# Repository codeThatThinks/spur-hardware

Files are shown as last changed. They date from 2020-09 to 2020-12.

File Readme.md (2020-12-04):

# spur-hardware

A physical UEFI boot switch -- PCB design files.

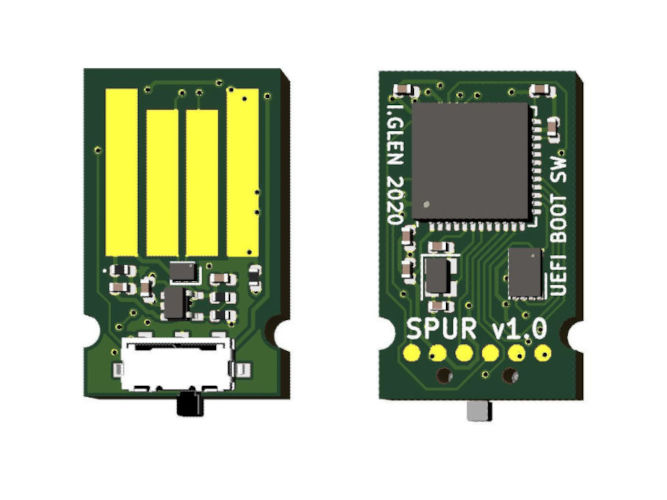
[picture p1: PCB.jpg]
PCB


## Theory of Operation

Spur appears as a virtual USB mass storage device and acts as a first-stage UEFI bootloader. This bootloader loads a specific boot entry in the system UEFI table depending on the position of a physical switch on the device.

A 1MB SPI NOR flash chip contains the FAT32 filesystem on which the UEFI bootloader lives. An STM32F4 microcontroller provides read/write access to the flash over USB. In addition, it presents a virtual file which is read by the bootloader to determine the state of the physical switch.

## License

The MIT License

Copyright 2020 Ian Glen

Permission is hereby granted, free of charge, to any person obtaining a copy of this software and associated documentation files (the "Software"), to deal in the Software without restriction, including without limitation the rights to use, copy, modify, merge, publish, distribute, sublicense, and/or sell copies of the Software, and to permit persons to whom the Software is furnished to do so, subject to the following conditions:

The above copyright notice and this permission notice shall be included in all copies or substantial portions of the Software.

THE SOFTWARE IS PROVIDED "AS IS", WITHOUT WARRANTY OF ANY KIND, EXPRESS OR IMPLIED, INCLUDING BUT NOT LIMITED TO THE WARRANTIES OF MERCHANTABILITY, FITNESS FOR A PARTICULAR PURPOSE AND NONINFRINGEMENT. IN NO EVENT SHALL THE AUTHORS OR COPYRIGHT HOLDERS BE LIABLE FOR ANY CLAIM, DAMAGES OR OTHER LIABILITY, WHETHER IN AN ACTION OF CONTRACT, TORT OR OTHERWISE, ARISING FROM, OUT OF OR IN CONNECTION WITH THE SOFTWARE OR THE USE OR OTHER DEALINGS IN THE SOFTWARE.

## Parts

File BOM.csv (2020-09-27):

Spur v1.0 BOM
Qty. | Refdes | Description | Value | Package | Manufacturer | Manufacturer P/N | Digikey P/N | Unit Price @ Qty 1 | Price @ Qty 1 | Unit Price @ Qty 100 | Price @ Qty 100
2 | C1, C2 | Capacitor, ceramic, 6.3V | 1u | 0402 | Samsung | CL05A105KQ5NNNC | 1276-1010-1-ND | $0.10000 | $0.20 | $0.00870 | $0.02
5 | C3, C7, C8, C9, C10 | Capacitor, ceramic, 6.3V | 0.1u | 0402 | Samsung | CL05A104KQ5NNNC | 1276-1442-1-ND | $0.10000 | $0.50 | $0.00850 | $0.04
2 | C4, C5 | Capacitor, ceramic, 50V | 4p | 0402 | Yageo | CC0402BRNPO9BN4R0 | 311-3705-1-ND | $0.10000 | $0.20 | $0.01760 | $0.04
1 | C6 | Capacitor, ceramic, 10V | 4.7u | 0402 | Samsung | CL05A475MP5NRNC | 1276-1482-1-ND | $0.10000 | $0.10 | $0.00336 | $0.00
1 | D1 | Zener diode, ESD |  | 0402 | ON Semi | NSPU3051N2T5G | NSPU3051N2T5GOSCT-ND | $0.36000 | $0.36 | $0.13440 | $0.13
1 | D2 | Diode array, ESD, 2 channel |  | SOT-886 | Nexperia | PRTR5V0U2F,115 | 1727-4161-1-ND | $0.49000 | $0.49 | $0.25500 | $0.26
1 | PCB1 | Bare PCB, 2 layer, 0.6mm, 1oz, ENIG |  |  | JLCPCB |  |  | $3.60000 | $3.60 | $0.49500 | $0.50
2 | R2, R3 | Resistor, thick film, 1%, 1/16W | 10K | 0402 | Yageo | RC0402FR-0710KL | 311-10.0KLRCT-ND | $0.10000 | $0.20 | $0.00580 | $0.01
1 | R1 | Resistor, thick film, 1%, 1/16W | 23K | 0402 | Yageo | RC0402FR-0722KL | 311-22.0KLRCT-ND | $0.10000 | $0.10 | $0.00580 | $0.01
1 | SW1 | Slide switch, SPDT |  | JS102000SAQN | C&K | JS102000SAQN | 401-2005-1-ND | $0.71000 | $0.71 | $0.56960 | $0.57
1 | U1 | Linear regulator, adjustable, 150mA |  | SOT-353 | Microchip | MIC5377YC5-TR | 576-3358-1-ND | $0.26000 | $0.26 | $0.20000 | $0.20
1 | U2 | Flash memory, NOR, SPI, 1MiB |  | 8-UDFN | Adesto | AT25SF081B-MAHB-T | 1265-AT25SF081B-MAHB-TCT-ND | $0.40000 | $0.40 | $0.32560 | $0.33
1 | U3 | Microcontroller, 128KiB flash |  | 48-UFQFN | STmicro | STM32F401CBU6 | 497-17425-ND | $4.96000 | $4.96 | $3.64690 | $3.65
1 | Y1 | Crystal, 24MHz, Cl=12pF |  | 4-SMD | Murata | XRCGB24M000F1H03R0 | 490-18289-1-ND | $0.44000 | $0.44 | $0.29100 | $0.29
 |  |  |  |  |  |  |  | Price @ Qty 1: | $12.52 | Price @ Qty 100: | $6.03

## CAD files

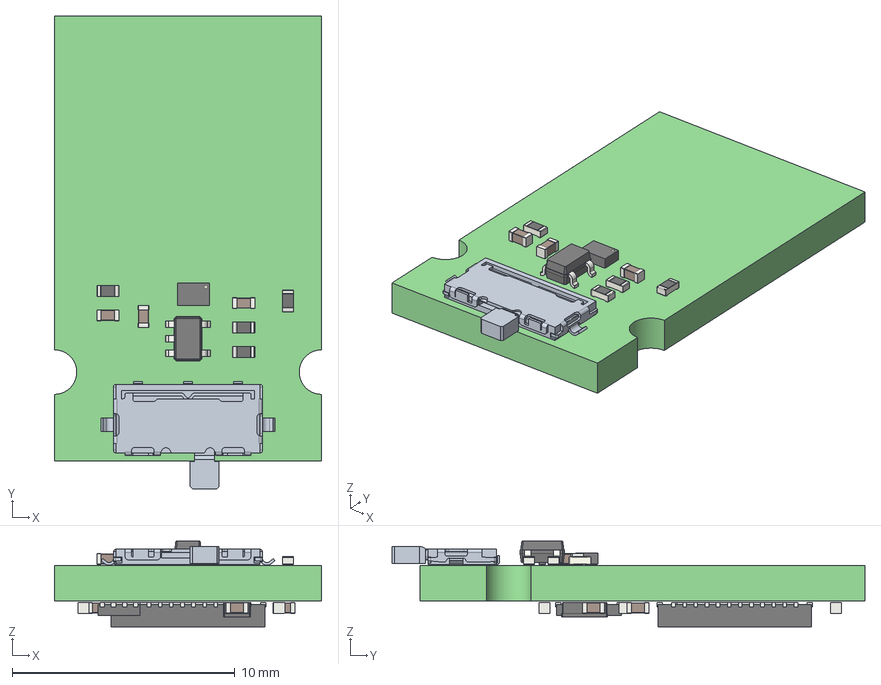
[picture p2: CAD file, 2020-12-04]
fab/spur.step
12.0 x 21.2 x 3.85 mm
js102000saqn

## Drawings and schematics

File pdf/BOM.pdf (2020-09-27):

# Spur v1.0 BOM

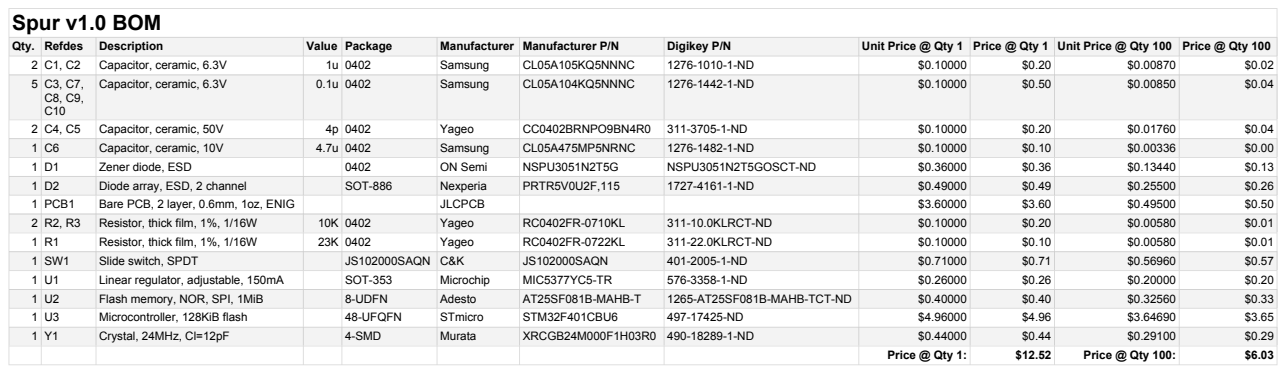
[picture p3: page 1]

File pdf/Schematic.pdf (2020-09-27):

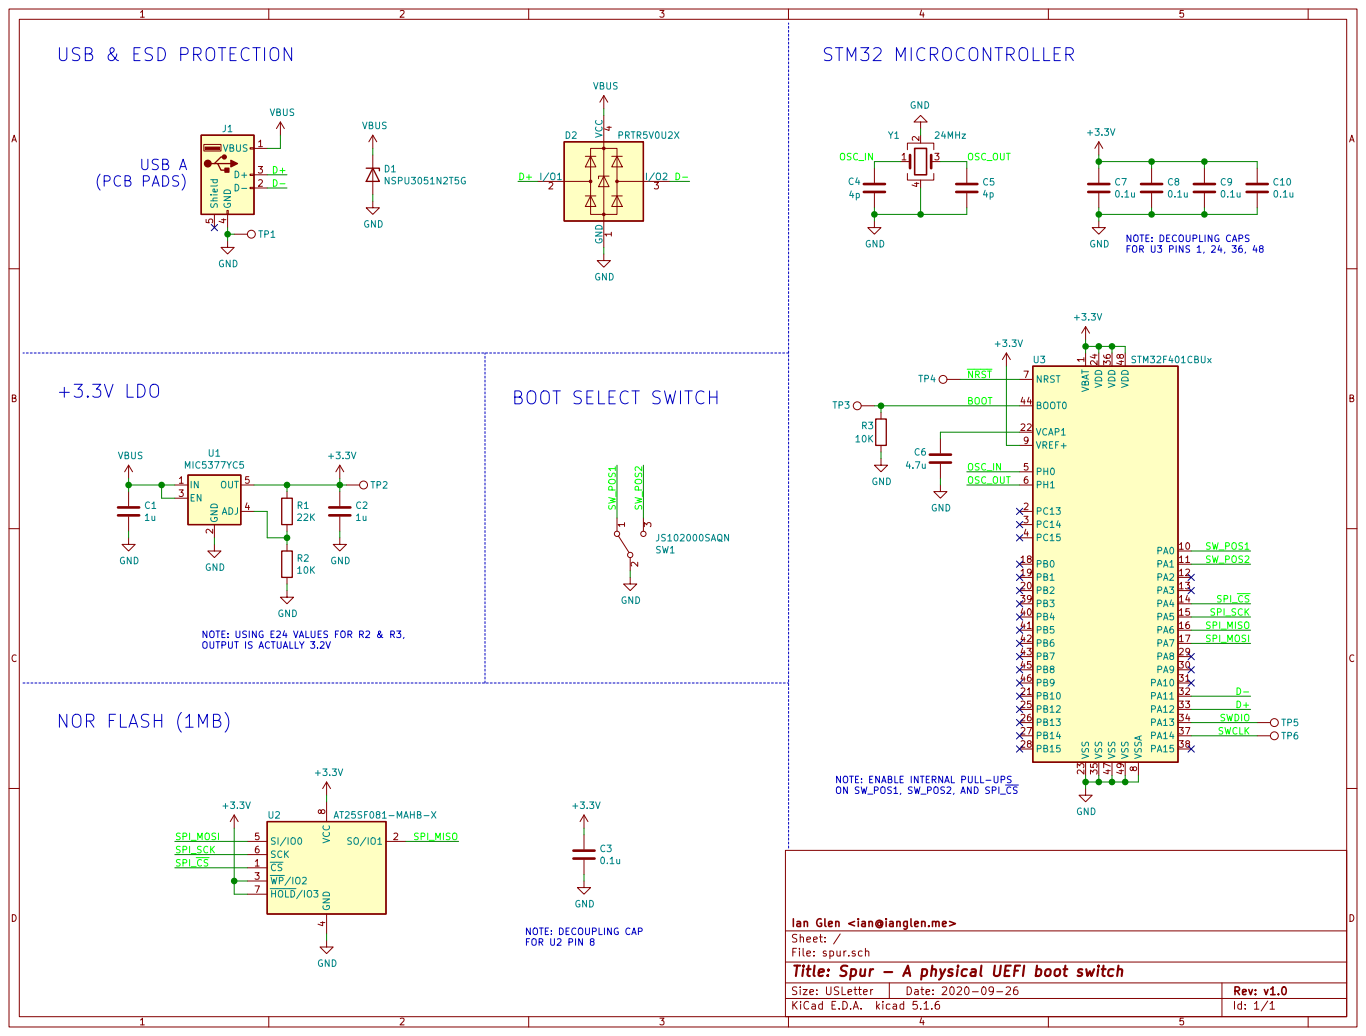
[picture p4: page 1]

2 EN 3 ADJ 4 OUT 5 U1 MIC5377YC5 GND GND1

FOR U3 PINS 1, 24, 36, 48 BOOT SELECT SWITCH

1 VCAP1 22 VDD 24 VDD 36 VDD 48 VREF+ 9 VSS 23 VSS 35 VSS 47 VSS 49 VSSA

Ian Glen <ian@ianglen.me> R1

NOTE: USING E24 VALUES FOR R2 & R3, OUTPUT IS ACTUALLY 3.2V NOR FLASH (1MB)

4 SI/IO0 5 SCK 6 HOLD/IO3 7 VCC

File: spur.sch Sheet: /
Id: 1/1 Title: Spur - A physical UEFI boot switch

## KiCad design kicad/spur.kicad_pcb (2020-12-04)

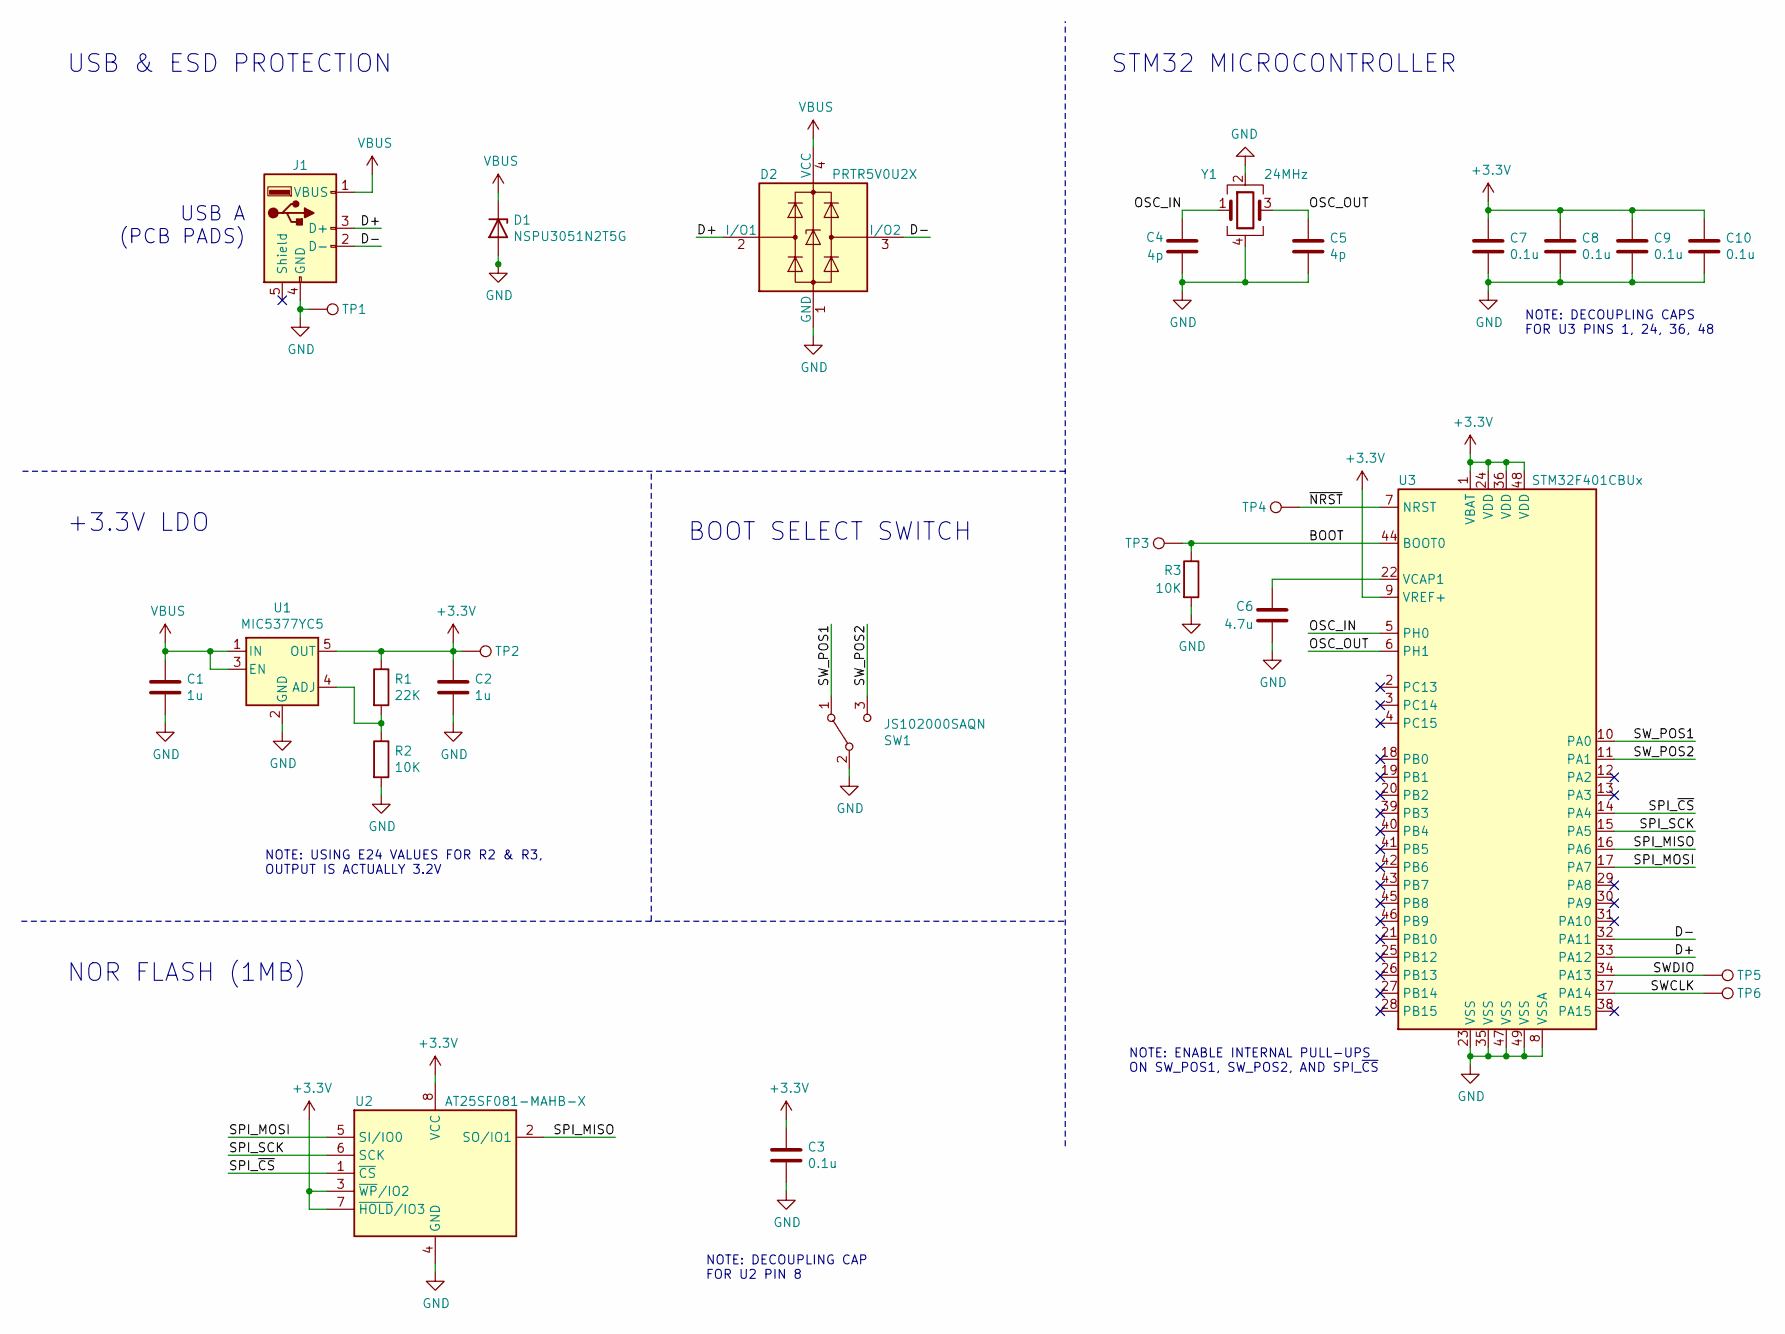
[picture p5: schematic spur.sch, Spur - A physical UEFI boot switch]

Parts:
C1, C2: 1u; C_0402_1005Metric
C3, C7, C8, C9, C10: 0.1u; C_0402_1005Metric
C4, C5: 4p; C_0402_1005Metric
C6: 4.7u; C_0402_1005Metric
D1: NSPU3051N2T5G; D_0402_1005Metric
D2: PRTR5V0U2X; SOT-886
J1: USB_A; USB_A_pads
R1: 22K; R_0402_1005Metric
R2, R3: 10K; R_0402_1005Metric
SW1: JS102000SAQN; SW_SPDT_CK-JS102000SAQN
TP1: GND; TestPoint_Pad_D1.0mm
TP2: 3V3; TestPoint_Pad_D1.0mm
TP3: BOOT; TestPoint_Pad_D1.0mm
TP4: NRST; TestPoint_Pad_D1.0mm
TP5: SWDIO; TestPoint_Pad_D1.0mm
TP6: SWCLK; TestPoint_Pad_D1.0mm
U1: MIC5377YC5; SOT-353_SC-70-5
U2: AT25SF081-MAHB-X; SON-8-1EP_3x2mm_P0.5mm_EP0.2x1.6mm
U3: STM32F401CBUx; QFN-48-1EP_7x7mm_P0.5mm_EP5.6x5.6mm
Y1: 24MHz; Crystal_SMD_2016-4Pin_2.0x1.6mm

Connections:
+3V3: C2.1, C3.1, C7.1, C8.1, C9.1, C10.1, R1.1, TP2.1, U1.5 (OUT), U2.3 (~WP~/IO2), U2.7 (~HOLD~/IO3), U2.8 (VCC), U3.1 (VBAT), U3.9 (VREF+), U3.24 (VDD), U3.36 (VDD), U3.48 (VDD)
/BOOT: R3.1, TP3.1, U3.44 (BOOT0)
/D+: D2.2 (I/O1), J1.3 (D+), U3.33 (PA12)
/D-: D2.3 (I/O2), J1.2 (D-), U3.32 (PA11)
/OSC_IN: C4.1, U3.5 (PH0), Y1.1
/OSC_OUT: C5.1, U3.6 (PH1), Y1.3
/SPI_MISO: U2.2 (SO/IO1), U3.16 (PA6)
/SPI_MOSI: U2.5 (SI/IO0), U3.17 (PA7)
/SPI_SCK: U2.6 (SCK), U3.15 (PA5)
/SPI_~CS: U2.1 (~CS), U3.14 (PA4)
/SWCLK: TP6.1, U3.37 (PA14)
/SWDIO: TP5.1, U3.34 (PA13)
/SW_POS1: SW1.1 (A), U3.10 (PA0)
/SW_POS2: SW1.3 (C), U3.11 (PA1)
/~NRST: TP4.1, U3.7 (NRST)
GND: C1.2, C2.2, C3.2, C4.2, C5.2, C6.2, C7.2, C8.2, C9.2, C10.2, D1.2 (A), D2.1 (GND), J1.4 (GND), R2.2, R3.2, SW1.2 (B), TP1.1, U1.2 (GND), U2.4 (GND), U3.8 (VSSA), U3.23 (VSS), U3.35 (VSS), U3.47 (VSS), U3.49 (VSS), Y1.2, Y1.4
unnamed: C6.1, U3.22 (VCAP1)
unnamed: R1.2, R2.1, U1.4 (ADJ)
VBUS: C1.1, D1.1 (K), D2.4 (VCC), J1.1 (VBUS), U1.1 (IN), U1.3 (EN)

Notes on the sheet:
USB A (PCB PADS)
USB & ESD PROTECTION
STM32 MICROCONTROLLER
NOR FLASH (1MB)
+3.3V LDO
BOOT SELECT SWITCH
NOTE: DECOUPLING CAP FOR U2 PIN 8
NOTE: DECOUPLING CAPS FOR U3 PINS 1, 24, 36, 48
NOTE: USING E24 VALUES FOR R2 & R3, OUTPUT IS ACTUALLY 3.2V
NOTE: ENABLE INTERNAL PULL-UPS ON SW_POS1, SW_POS2, AND SPI_~CS

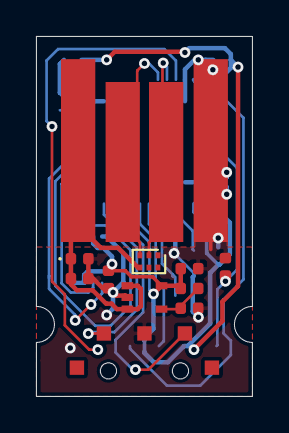
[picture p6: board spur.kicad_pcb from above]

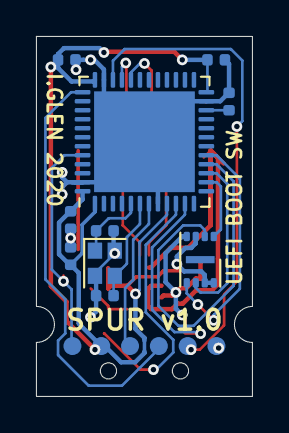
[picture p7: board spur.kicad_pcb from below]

Board: 2 copper layers, 12.0 x 20.0 mm, 27 parts (16 on the bottom side), 19 nets.

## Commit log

2020-09-22 Remove UART test points
    [spur.sch]
2020-09-23 Move switch input pins
    [spur.sch]
2020-09-25 Update R2 value, fix C1 & C2 symbols, improve schematic notes
    [spur.sch]
2020-09-25 Add passives to BOM
    [BOM.csv, BOM.xlsx]
2020-09-25 Add PCB to BOM
    [BOM.csv, BOM.xlsx]
2020-09-27 Switch to internal pull-ups, remove 4.7uF bulk cap
    [spur.sch]
2020-09-27 Remove pull-ups, bulk cap from BOM
    [BOM.csv, BOM.xlsx]
2020-09-30 Add custom footprint for flash chip
    [spur.sch]
2020-12-04 Add PCB layout
    [spur-B_Cu.gbr, spur-B_Mask.gbr, spur-B_Paste.gbr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]
